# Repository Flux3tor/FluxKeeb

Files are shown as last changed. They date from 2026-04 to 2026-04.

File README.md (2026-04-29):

# FluxKeeb

FluxPad is a custom 65% keyboard powered by the Raspberry Pi Pico  
It features a Raspberry Pi Pico as its main controller, Akko V5 Creamy Yellow Pro as the switches and a compact 3D-printed case!

---

## Why did I make it?

So my first project was actually a Macropad, but I was too lazy to make more projects and ofcourse too lazy to do this also, but I need a keyboard badly as my current one broke, so I made it instead of spending money to buy one

---

## Project Images

### Schematic
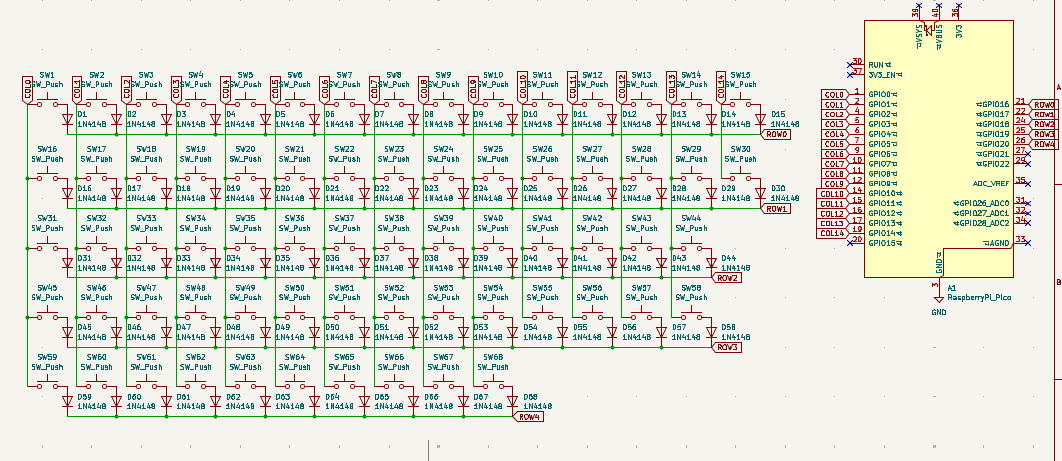
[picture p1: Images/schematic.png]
Schematic


### PCB
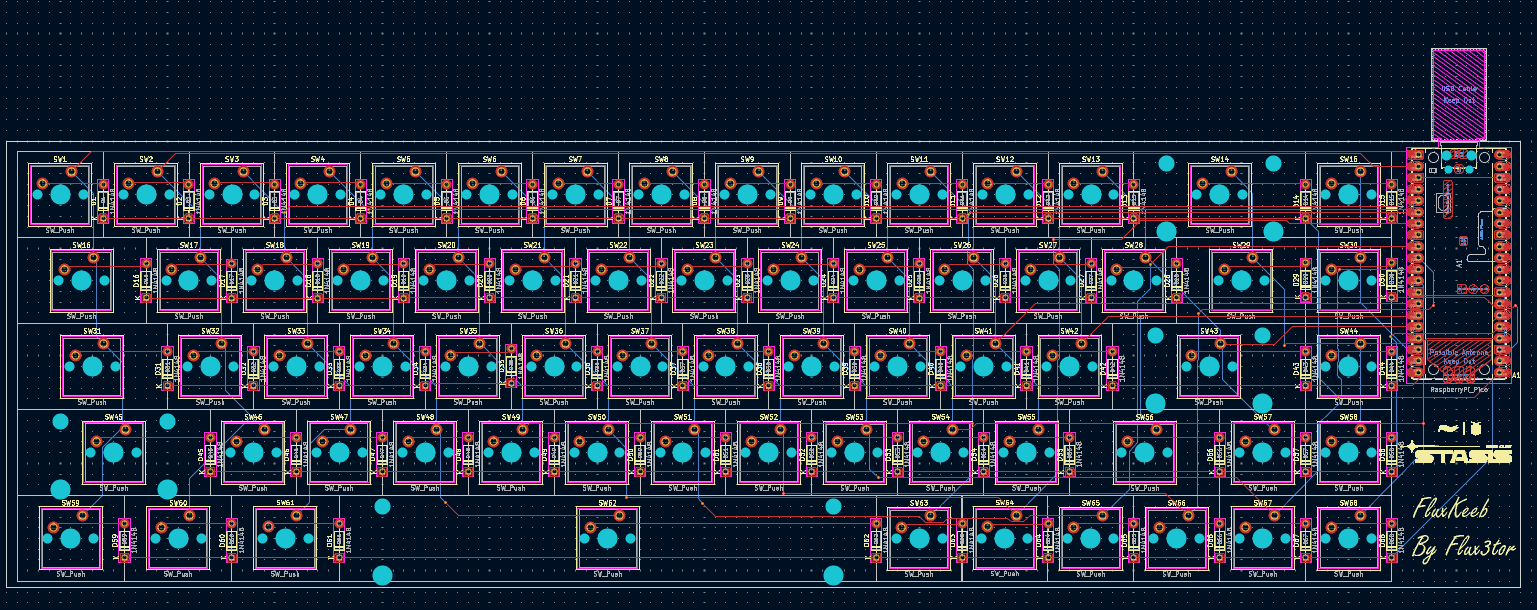
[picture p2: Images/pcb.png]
PCB


### Case Design
#### Bottom Case
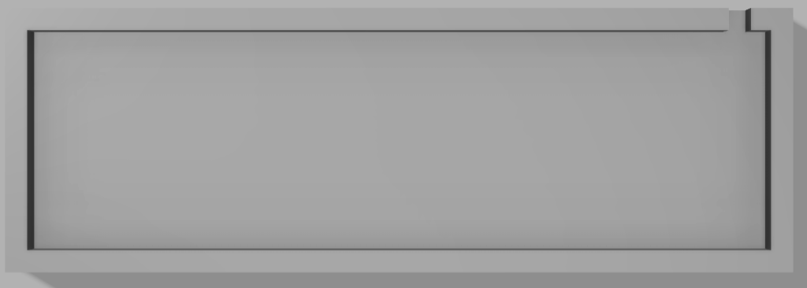
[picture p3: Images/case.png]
case_bottom


### Final Layout
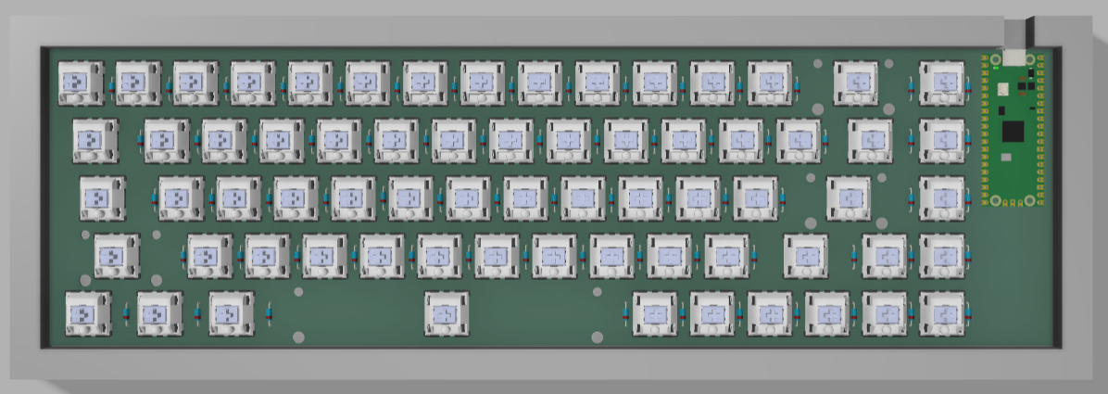
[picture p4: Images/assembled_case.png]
Final


---

Features:
- 68 keys
- Raspberry Pi Pico
- Customised layout
- QMK firmware
- FluxKeeb Branded PCB
- Custom case

---

## BOM
|Name |Purpose |Quantity|Total Cost (USD)|Link |Distributor |
|---|---|---|---|---|---|
|Akko V5 Creamy Yellow Pro Switch (Pack of 45) |switches for the keyboard! |2 |25.77 |https://stackskb.com/store/akko-v5-creamy-yellow-pro-switch-pack-of-45/ |StacksKB |
|Veekos Gradient Keycaps (Cherry Profile) (135 keys) (Blue) |keycaps for the keyboard's switches! |1 |13.96 |https://stackskb.com/store/veekos-gradient-keycaps-cherry-profile-135-keys/ |StacksKB |
|Durock Clear Screw-In Stabilizers V2 (4+1 w/ 6.25u spacebar)|Stabilizers for the big keys like spacebar |1 |17.14 |https://stackskb.com/store/durock-clear-screw-in-stabilizers-v2/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 |StacksKB |
|1N4148 Diode (100 Pieces) |Diodes for the switch matrix! |1 |1.60 |https://www.amazon.in/gp/product/B084ZP5BJ3 |Amazon |
|Raspberry Pi Pico |main controller for the keyboard! |1 |5.36 |https://robu.in/product/raspberry-pi-pico-with-headers/ |Robu |
|PCB |pcb for the keyboard! |5 |9.00 |https://www.allpcb.com/ |ALLPCB |
|Case | shipping for the case|1 |5.00 |https://printlegion.hackclub.com/ |Printing Legion|

## Shipping
Amazon + StacksKB = ~$1.5

Printing Legion = ~$5

Total Shipping = $6.5

## Total Pricing
The total price comes out to be **7,532 INR ($80.93) with shipping**

## Build Process

I finally finished making the project did all the soldering and connected everything properly had to be careful with the joints so nothing messes up, after that i assembled the whole thing and checked all the connections tested it and yeah it actually worked which was nice

Overall it turned out good and now i actually get soldering way better than before!

---

## Final Build

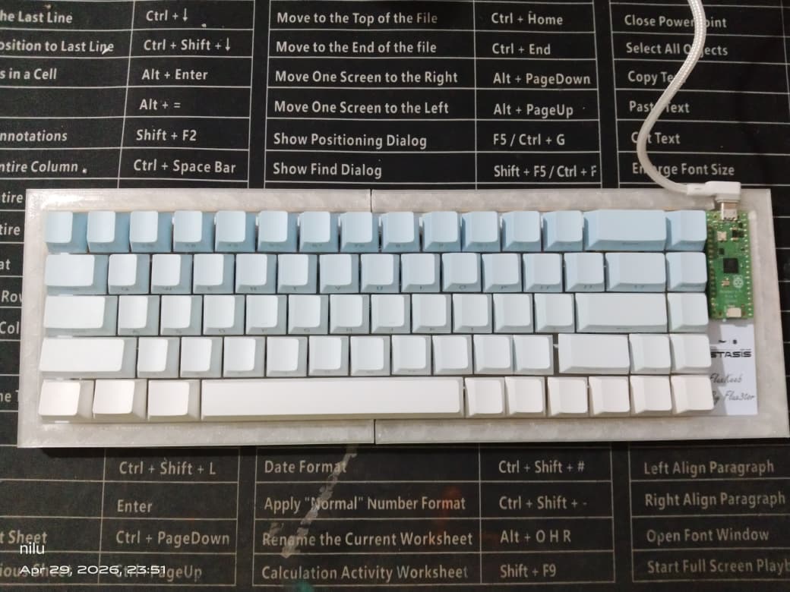
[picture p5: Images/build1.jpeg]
Build1


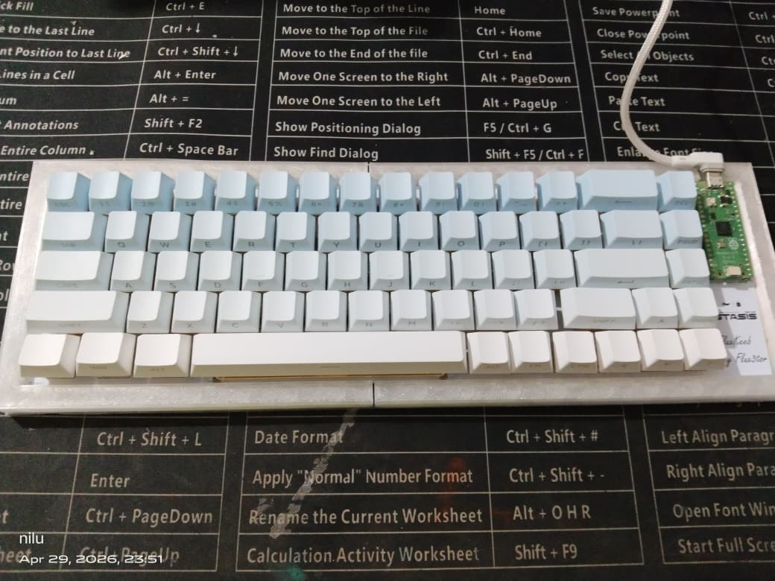
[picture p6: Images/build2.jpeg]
Build2


---

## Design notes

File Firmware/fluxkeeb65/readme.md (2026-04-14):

# fluxkeeb65

fluxkeeb65

*A short description of the keyboard/project*

* Keyboard Maintainer: [Flux3tor](https://github.com/Flux3tor)
* Hardware Supported: *The PCBs, controllers supported*
* Hardware Availability: *Links to where you can find this hardware*

Make example for this keyboard (after setting up your build environment):

    make fluxkeeb65:default

Flashing example for this keyboard:

    make fluxkeeb65:default:flash

See the [build environment setup](https://docs.qmk.fm/#/getting_started_build_tools) and the [make instructions](https://docs.qmk.fm/#/getting_started_make_guide) for more information. Brand new to QMK? Start with our [Complete Newbs Guide](https://docs.qmk.fm/#/newbs).

## Bootloader

Enter the bootloader in 3 ways:

* **Bootmagic reset**: Hold down the key at (0,0) in the matrix (usually the top left key or Escape) and plug in the keyboard
* **Physical reset button**: Briefly press the button on the back of the PCB - some may have pads you must short instead
* **Keycode in layout**: Press the key mapped to `QK_BOOT` if it is available

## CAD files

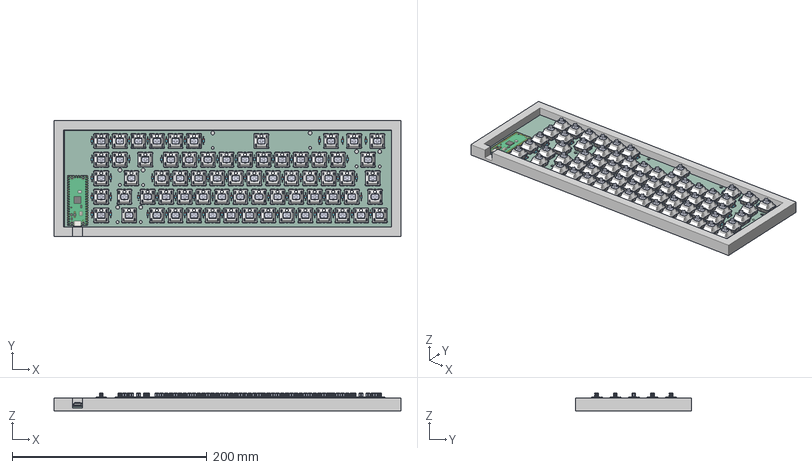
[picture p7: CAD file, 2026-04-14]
CAD/FluxKeeb Case Assembled.step
356.2 x 119.5 x 18.1 mm

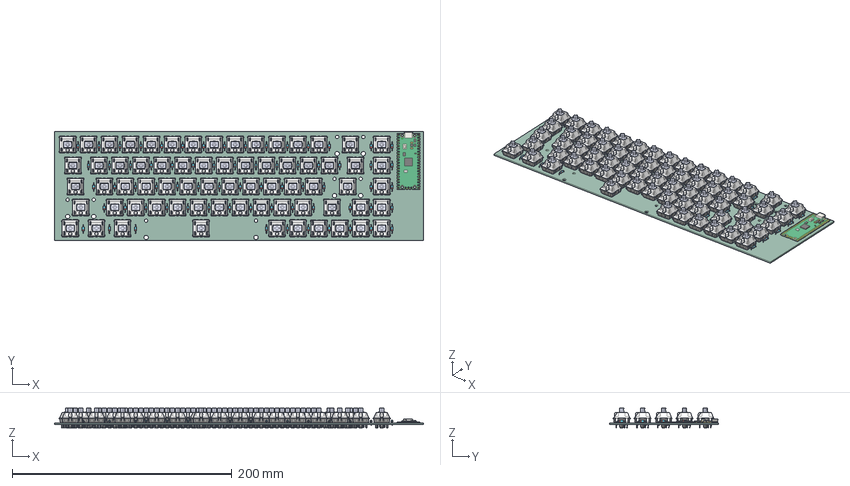
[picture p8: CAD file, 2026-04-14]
PCB/FluxKeeb.step
335.8 x 99.1 x 18.0 mm
Bottom x 68
Pulsador x 68
Top x 68
Pieza5^Cherry MX x 68
Pin1 x 68
Pin2 x 68
Led 3mm_trans x 68
D_DO-35_SOD27_P7.62mm_Horizontal x 68
RaspberryPi_Pico_Module_KiCad
FluxKeeb_PCB

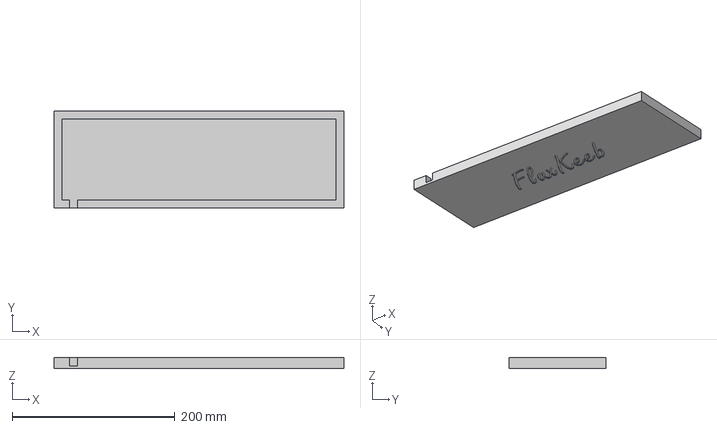
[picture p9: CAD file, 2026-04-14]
CAD/FluxKeeb Case.step
356.2 x 119.5 x 13.0 mm

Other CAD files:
CAD/FluxKeeb Case Assembled.f3z
CAD/FluxKeeb Case.f3d

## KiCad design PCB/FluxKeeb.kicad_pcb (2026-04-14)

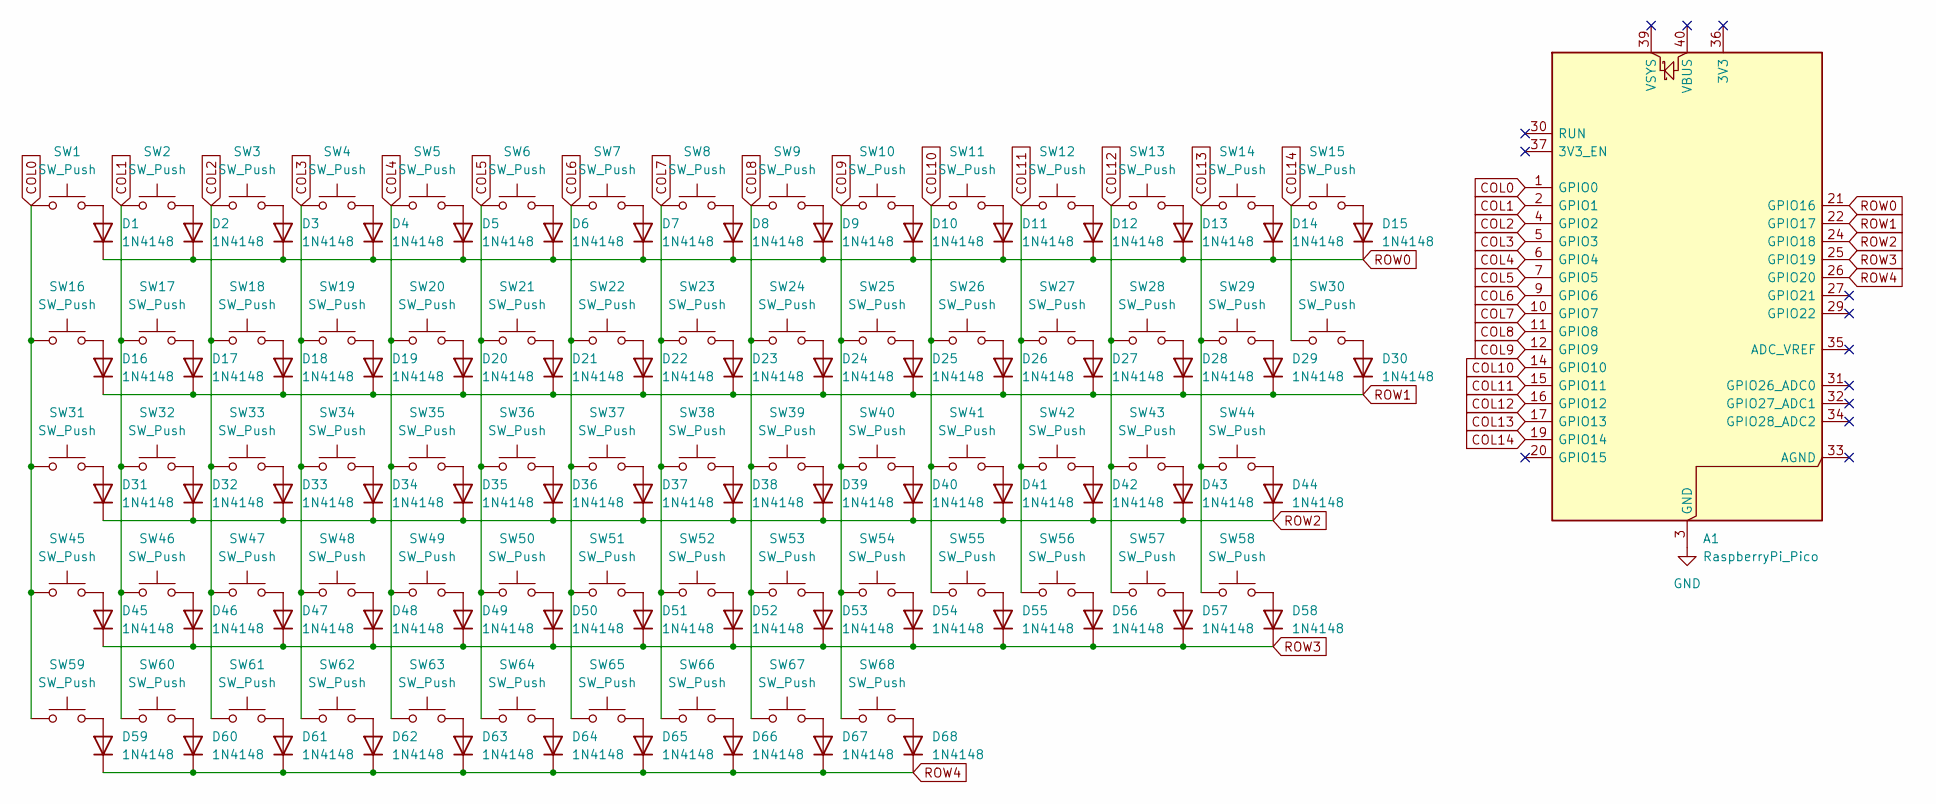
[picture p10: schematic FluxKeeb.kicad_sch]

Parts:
A1: RaspberryPi_Pico; RaspberryPi_Pico_Common_Unspecified
D1, D2, D3, D4, D5, D6, D7, D8, D9, D10, D11, D12, D13, D14, D15, D16, D17, D18, D19, D20, D21, D22, D23, D24, D25, D26, D27, D28, D29, D30, D31, D32, D33, D34, D35, D36, D37, D38, D39, D40, D41, D42, D43, D44, D45, D46, D47, D48, D49, D50, D51, D52, D53, D54, D55, D56, D57, D58, D59, D60, D61, D62, D63, D64, D65, D66, D67, D68: 1N4148; D_DO-35_SOD27_P7.62mm_Horizontal
SW1, SW2, SW3, SW4, SW5, SW6, SW7, SW8, SW9, SW10, SW11, SW12, SW13, SW15, SW17, SW18, SW19, SW20, SW21, SW22, SW23, SW24, SW25, SW26, SW27, SW28, SW30, SW32, SW33, SW34, SW35, SW36, SW37, SW38, SW39, SW40, SW41, SW42, SW44, SW46, SW47, SW48, SW49, SW50, SW51, SW52, SW53, SW54, SW55, SW57, SW58, SW63, SW64, SW65, SW66, SW67, SW68: SW_Push; SW_Cherry_MX_1.00u_PCB
SW14: SW_Push; SW_Cherry_MX_2.00u_PCB
SW16, SW29: SW_Push; SW_Cherry_MX_1.50u_PCB
SW31, SW56: SW_Push; SW_Cherry_MX_1.75u_PCB
SW43, SW45: SW_Push; SW_Cherry_MX_2.25u_PCB
SW59, SW60, SW61: SW_Push; SW_Cherry_MX_1.25u_PCB
SW62: SW_Push; SW_Cherry_MX_6.25u_PCB

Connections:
COL0: A1.1 (GPIO0), SW1.1, SW16.1, SW31.1, SW45.1, SW59.1
COL1: A1.2 (GPIO1), SW2.1, SW17.1, SW32.1, SW46.1, SW60.1
COL2: A1.4 (GPIO2), SW3.1, SW18.1, SW33.1, SW47.1, SW61.1
COL3: A1.5 (GPIO3), SW4.1, SW19.1, SW34.1, SW48.1, SW62.1
COL4: A1.6 (GPIO4), SW5.1, SW20.1, SW35.1, SW49.1, SW63.1
COL5: A1.7 (GPIO5), SW6.1, SW21.1, SW36.1, SW50.1, SW64.1
COL6: A1.9 (GPIO6), SW7.1, SW22.1, SW37.1, SW51.1, SW65.1
COL7: A1.10 (GPIO7), SW8.1, SW23.1, SW38.1, SW52.1, SW66.1
COL8: A1.11 (GPIO8), SW9.1, SW24.1, SW39.1, SW53.1, SW67.1
COL9: A1.12 (GPIO9), SW10.1, SW25.1, SW40.1, SW54.1, SW68.1
COL10: A1.14 (GPIO10), SW11.1, SW26.1, SW41.1, SW55.1
COL11: A1.15 (GPIO11), SW12.1, SW27.1, SW42.1, SW56.1
COL12: A1.16 (GPIO12), SW13.1, SW28.1, SW43.1, SW57.1
COL13: A1.17 (GPIO13), SW14.1, SW29.1, SW44.1, SW58.1
COL14: A1.19 (GPIO14), SW15.1, SW30.1
GND: A1.3 (GND), A1.8 (GND), A1.13 (GND), A1.18 (GND), A1.23 (GND), A1.28 (GND), A1.38 (GND)
unnamed: D1.2 (A), SW1.2
unnamed: D2.2 (A), SW2.2
unnamed: D3.2 (A), SW3.2
unnamed: D4.2 (A), SW4.2
unnamed: D5.2 (A), SW5.2
unnamed: D6.2 (A), SW6.2
unnamed: D7.2 (A), SW7.2
unnamed: D8.2 (A), SW8.2
unnamed: D9.2 (A), SW9.2
unnamed: D10.2 (A), SW10.2
unnamed: D11.2 (A), SW11.2
unnamed: D12.2 (A), SW12.2
unnamed: D13.2 (A), SW13.2
unnamed: D14.2 (A), SW14.2
unnamed: D15.2 (A), SW15.2
unnamed: D16.2 (A), SW16.2
unnamed: D17.2 (A), SW17.2
unnamed: D18.2 (A), SW18.2
unnamed: D19.2 (A), SW19.2
unnamed: D20.2 (A), SW20.2
unnamed: D21.2 (A), SW21.2
unnamed: D22.2 (A), SW22.2
unnamed: D23.2 (A), SW23.2
unnamed: D24.2 (A), SW24.2
unnamed: D25.2 (A), SW25.2
unnamed: D26.2 (A), SW26.2
unnamed: D27.2 (A), SW27.2
unnamed: D28.2 (A), SW28.2
unnamed: D29.2 (A), SW29.2
unnamed: D30.2 (A), SW30.2
unnamed: D31.2 (A), SW31.2
unnamed: D32.2 (A), SW32.2
unnamed: D33.2 (A), SW33.2
unnamed: D34.2 (A), SW34.2
unnamed: D35.2 (A), SW35.2
unnamed: D36.2 (A), SW36.2
unnamed: D37.2 (A), SW37.2
unnamed: D38.2 (A), SW38.2
unnamed: D39.2 (A), SW39.2
unnamed: D40.2 (A), SW40.2
unnamed: D41.2 (A), SW41.2
unnamed: D42.2 (A), SW42.2
unnamed: D43.2 (A), SW43.2
unnamed: D44.2 (A), SW44.2
unnamed: D45.2 (A), SW45.2
unnamed: D46.2 (A), SW46.2
unnamed: D47.2 (A), SW47.2
unnamed: D48.2 (A), SW48.2
unnamed: D49.2 (A), SW49.2
unnamed: D50.2 (A), SW50.2
unnamed: D51.2 (A), SW51.2
unnamed: D52.2 (A), SW52.2
unnamed: D53.2 (A), SW53.2
unnamed: D54.2 (A), SW54.2
unnamed: D55.2 (A), SW55.2
unnamed: D56.2 (A), SW56.2
unnamed: D57.2 (A), SW57.2
unnamed: D58.2 (A), SW58.2
unnamed: D59.2 (A), SW59.2
unnamed: D60.2 (A), SW60.2
unnamed: D61.2 (A), SW61.2
unnamed: D62.2 (A), SW62.2
unnamed: D63.2 (A), SW63.2
unnamed: D64.2 (A), SW64.2
unnamed: D65.2 (A), SW65.2
unnamed: D66.2 (A), SW66.2
unnamed: D67.2 (A), SW67.2
unnamed: D68.2 (A), SW68.2
ROW0: A1.21 (GPIO16), D1.1 (K), D2.1 (K), D3.1 (K), D4.1 (K), D5.1 (K), D6.1 (K), D7.1 (K), D8.1 (K), D9.1 (K), D10.1 (K), D11.1 (K), D12.1 (K), D13.1 (K), D14.1 (K), D15.1 (K)
ROW1: A1.22 (GPIO17), D16.1 (K), D17.1 (K), D18.1 (K), D19.1 (K), D20.1 (K), D21.1 (K), D22.1 (K), D23.1 (K), D24.1 (K), D25.1 (K), D26.1 (K), D27.1 (K), D28.1 (K), D29.1 (K), D30.1 (K)
ROW2: A1.24 (GPIO18), D31.1 (K), D32.1 (K), D33.1 (K), D34.1 (K), D35.1 (K), D36.1 (K), D37.1 (K), D38.1 (K), D39.1 (K), D40.1 (K), D41.1 (K), D42.1 (K), D43.1 (K), D44.1 (K)
ROW3: A1.25 (GPIO19), D45.1 (K), D46.1 (K), D47.1 (K), D48.1 (K), D49.1 (K), D50.1 (K), D51.1 (K), D52.1 (K), D53.1 (K), D54.1 (K), D55.1 (K), D56.1 (K), D57.1 (K), D58.1 (K)
ROW4: A1.26 (GPIO20), D59.1 (K), D60.1 (K), D61.1 (K), D62.1 (K), D63.1 (K), D64.1 (K), D65.1 (K), D66.1 (K), D67.1 (K), D68.1 (K)

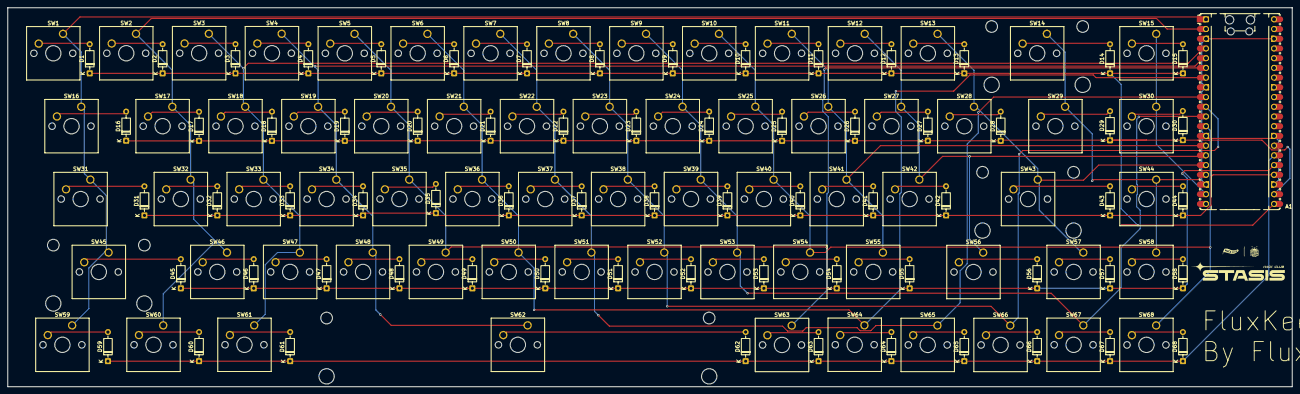
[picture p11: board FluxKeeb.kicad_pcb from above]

Board: 2 copper layers, 335.8 x 99.1 mm, 138 parts (0 on the bottom side), 89 nets.

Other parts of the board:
img1: LOGO
